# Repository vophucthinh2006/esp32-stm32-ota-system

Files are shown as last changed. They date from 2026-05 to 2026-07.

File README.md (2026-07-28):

# ESP32 to STM32 Dual-MCU OTA Update System

A robust dual-MCU Firmware Over-The-Air (OTA) update system. This project utilizes an ESP32 as a network-connected gateway that fetches firmware binaries from a GitHub repository via HTTPS and flashes them onto an STM32F103C8T6 target microcontroller via a custom bare-metal UART bootloader protocol.

---

## 1. Project Overview

This system provides a reliable, remote firmware deployment pipeline for distributed edge devices. The architecture clearly separates the network gateway layer from the core application execution layer:

* **ESP32 (Gateway):** Periodically polls GitHub using HTTPS HEAD requests, monitors the `ETag` header for remote binary changes, streams 128-byte chunk buffers over SSL, and acts as the UART Master to program the host.
* **STM32F103 (Application Host):** Runs a custom **Bare-Metal Bootloader** (direct register access) that verifies a 2-step handshake, erases designated internal flash pages, calculates 16-bit CRC on incoming packets, programs internal flash, and safely jumps to user application space.

---

## 2. Key Features & Implementation Achievements

* **Dynamic Update Detection:** Uses HTTP `ETag` tracking instead of full binary downloads to detect remote firmware updates, drastically reducing bandwidth and power consumption.
* **Cache-Busting Mechanism:** Appends a random `cache buster` parameter to query URLs to bypass proxy/CDN caching and guarantee fresh fetches.
* **Bare-Metal Reliability:** The STM32 bootloader is implemented entirely at the register level (No HAL, No LL, No RTOS), minimizing code footprint and eliminating library overhead.
* **Stream-Based Chunk Buffering:** Downloads and flashes firmware in 128-byte chunks, avoiding the need for large external flash/RAM storage.
* **Memory-Safe Padding:** Automates 128-byte alignment padding (`0xFF`) for non-full partial flash blocks at the end of the stream.
* **Hardware Status Indicators:** Dedicated LEDs provide real-time visual feedback (`LED_POWER`, `LED_NEW_VERSION`, `LED_LOADING`).

---

## 3. Hardware Overview & Pinout

### 3.1 Components & Modules
* **Gateway Microcontroller:** ESP32-DevKitC-32D.
* **Target Microcontroller:** STM32F103C8T6 (ARM Cortex-M3).
* **Power Management:** LM2596 Buck Converter Module (12V Battery Input → 5V System Power).
* **Power Control:** SW_SPDT Power Switch.
* **User Input:** SPST Push Button with RC filter (`C1 = 0.1µF`) for physical debouncing.

### 3.2 Pin Mapping

#### ESP32 Gateway Board:
| Pin Name | Function / Connection | Description |
| :--- | :--- | :--- |
| `IO32` | `LED_POWER` (`D1` via 220Ω) | Power-On Indicator |
| `IO17` | `LED_NEW_VERSION` (`D2` via 220Ω) | Remote update available on GitHub |
| `IO2` | `LED_LOADING` (`D3` via 220Ω) | Active flashing/erasing in progress |
| `IO4` | `SW1 Button` (Active-Low) | User trigger to start OTA update process |
| `TXD2` (`IO10`) | UART2 TX $\rightarrow$ STM32 RX | Serial Command & Payload Line |
| `RXD2` (`IO9`) | UART2 RX $\leftarrow$ STM32 TX | Serial ACK/NACK Response Line |

#### Target Communication Header (5-Pin Header):
| Pin | Function | Description |
| :--- | :--- | :--- |
| `1` | `VCC` | +5V Power Rail |
| `2` | `GND` | Ground Reference |
| `3` | `RxD` | UART Receive Line |
| `4` | `TxD` | UART Transmit Line |
| `5` | `Button` | Manual Boot Mode Trigger / Hardware Interlock |

---

## 4. Hardware Design & Schematics

### 4.1 Schematic Diagram
The custom carrier board schematic integrates power regulation, status LEDs, debounced input, and external headers.

<p align="center">
  ESP32 STM32 OTA System - Schematic
</p>

### 4.2 PCB Layout
Single-sided PCB design incorporating power planes, signal routing, and modular sub-board connections.

<p align="center">
  PCB Layout
</p>

---

## 5. Software Architecture & State Machines

### 5.1 System-Level Finite State Machine (End-to-End Workflow)
The complete interaction lifecycle between GitHub Cloud, ESP32 Gateway, and STM32 Target Microcontroller:

<p align="center">
  OTA Overall System State Machine
</p>

### 5.2 STM32 Bootloader Internal Operations
Detailed internal state processing, packet verification, and flash memory execution on the target STM32:

<p align="center">
  STM32 Bootloader Internal Execution Flow
</p>

---

## 6. UART Communication Protocol

All control frames and data packets transmitted from the ESP32 to the STM32 adhere to a structured protocol format:

### 6.1 Packet Structure
| Field | Size (Bytes) | Description / Value |
| :--- | :--- | :--- |
| **Start of Frame (SOF)** | 2 | Header Sync Bytes: `0xAA 0xBB` |
| **Command Code (CMD)** | 1 | `0x01` (START), `0x02` (ERASE), `0x03` (PROGRAM), `0x04` (JUMP) |
| **Data Length** | 1 | Payload byte length ($N \le 250$) |
| **Payload Data** | $N$ | Binary firmware slice or command parameters |
| **Checksum (CRC16)** | 2 | Big-Endian CCITT CRC-16 ($x^{16} + x^{12} + x^5 + 1$) |

### 6.2 Security Handshake Sequence
Before accepting flashing commands, the STM32 enforces a strict key validation handshake:
1. ESP32 sends `BL_UPDATE_KEY_1` (`0xCC`). STM32 validates and responds with `ACK` (`0x0A`).
2. ESP32 sends `BL_UPDATE_KEY_2` (`0xDD`). STM32 validates and responds with `ACK` (`0x0A`).
3. Upon completion, STM32 transitions to the verified bootloader receiving state.

### 6.3 Flashing Commands Breakdown
* `BL_START` (`0x01`): Resets internal flash write pointer (`FLASH_Page_Pointer`) to `APP_ADD_BASE` (`0x08002000`).
* `BL_ERASE` (`0x02`): Sequentially erases target application pages (Pages 8 to 63).
* `BL_PROGRAM` (`0x03`): Programs incoming 128-byte binary streams into Flash as 16-bit half-words and increments the memory pointer.
* `BL_JUMP` (`0x04`): Disables global interrupts, re-maps Vector Table (`SCB_VTOR` to `0x08002000`), sets Main Stack Pointer (`_Set_MSP`), and jumps to User Application Execution.

---

## 7. Flash Memory Mapping (STM32F103C8T6)

The internal 64KB Flash memory space is divided to segregate the immutable bootloader from the upgradable application space:

<p align="center">
  STM32 Bootloader Internal FLash Memory Mapping
</p>

---

## 8. Demo Video
Below is a short demo video illustrating the end-to-end OTA update process:

▶️ [ESP32 to STM32 Dual-MCU OTA Update - Demo Video](https://youtu.be/XsSUUxfZz8Y?si=K6gj_BpSvMdLIf3Q)

---

## 9. Build and Flash
**ESP32 Gateway Firmware**
* **Framework: ESP-IDF / Arduino Core for ESP32.**

* **Libraries:** WiFiClientSecure, HTTPClient.

**STM32 Bootloader**
* **Toolchain:** arm-none-eabi-gcc.

* **Build System:** CMake.

* **Programmer:** ST-Link V2.

* **Development Style:** Bare-metal direct register programming (No HAL / LL libraries used).

---

## 10. Performance & System Trade-offs
* **Baud Rate Selection (9600 bps):** Chosen to guarantee noise-immune, zero-error serial data transfer over unshielded wires between the gateway and target board without needing hardware RTS/CTS flow control.

* **Stream Buffering vs. External Storage:** Processing firmware in small 128-byte RAM buffers eliminates the physical footprint, cost, and power overhead of an external SPI Flash chip or SD card module.

* **Single-Bank Flashing:** Prioritizes maximum flash allocation for user applications (~56KB available out of 64KB) over dual-bank storage, relying on CRC checks and handshake verification to ensure update integrity.

---

## 11. Limitations and Future Improvements
* **Dual-Bank Architecture:** Adding external SPI flash to support rollback in case of power interruption during programming.

* **Hardware Reset Line:** Wiring an ESP32 GPIO directly to the STM32 NRST pin for automated hard-resets into bootloader mode.

* **Firmware Encryption:** Implementing AES-128/256 payload decryption on the STM32 to secure firmware against eavesdropping.

---

## 12. Author
**Author:** Vo Phuc Thinh

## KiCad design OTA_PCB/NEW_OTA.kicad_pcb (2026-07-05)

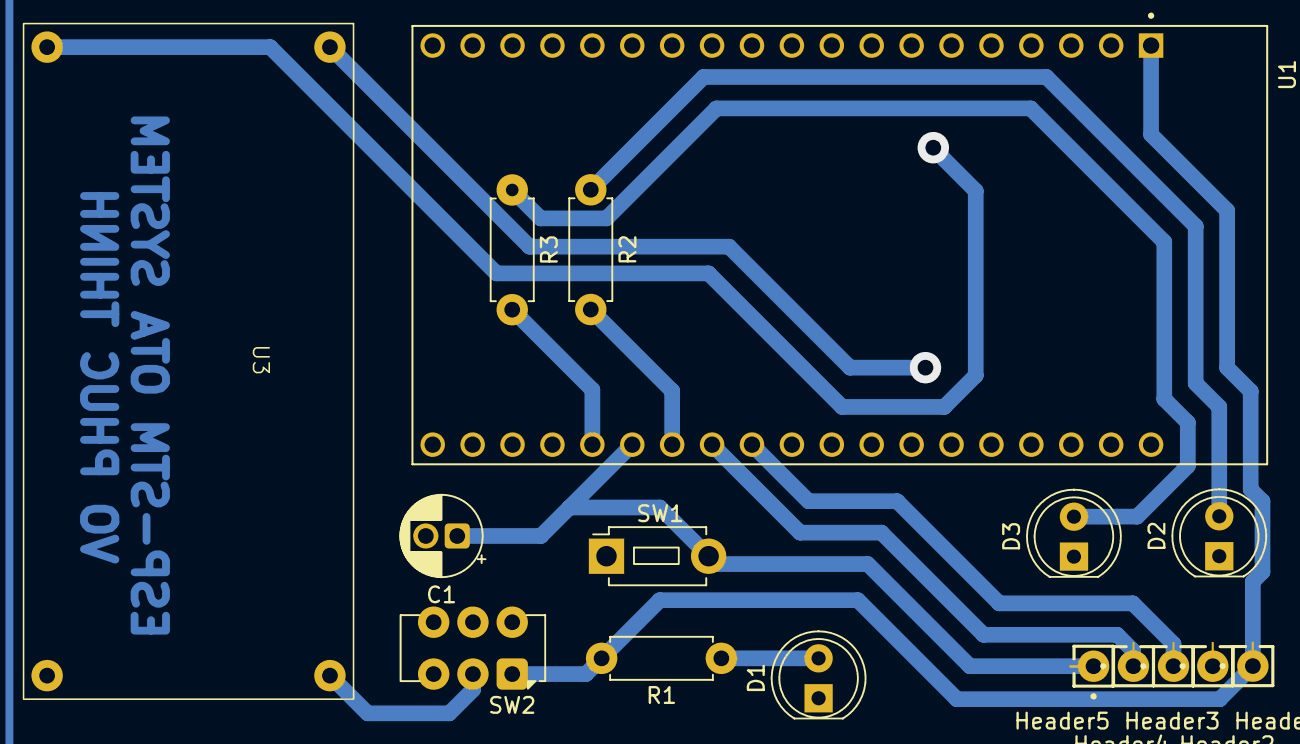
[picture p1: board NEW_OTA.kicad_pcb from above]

Board: 2 copper layers, 16 parts (0 on the bottom side), 11 nets.

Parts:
C1: 0.1uF; CP_Radial_D5.0mm_P2.00mm
D1, D2, D3: LED; LED_D5.0mm_Clear
Header1: VCC; SAMTEC_MTLW-101-08-S-S-330
Header2: GND; SAMTEC_MTLW-101-08-S-S-330
Header3: RXD; SAMTEC_MTLW-101-08-S-S-330
Header4: TXD; SAMTEC_MTLW-101-08-S-S-330
Header5: Button; SAMTEC_MTLW-101-08-S-S-330
R1, R2, R3: 220; R_Axial_DIN0207_L6.3mm_D2.5mm_P7.62mm_Horizontal
SW1: Button; SW_PUSH_1P1T_6x3.5mm_H4.3_APEM_MJTP1243
SW2: SW_SPDT; SW_CK_JS202011AQN_DPDT_Angled
U1: ESP32-DEVKITC-32D; MODULE_ESP32-DEVKITC-32D
U3: LM2596-Buck-Converter-Module; LM2596 Buck Converter Module

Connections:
/Button: C1.1, Header5.01 (01_01), SW1.1, U1.J3-14 (IO0)
/Source: SW2.2 (B), U3.1 (OUT+)
/UART2_RX: Header4.01 (01_01), U1.J3-12 (IO16)
/UART2_TX: Header3.01 (01_01), U1.J3-11 (IO17)
/VCC: Header1.01 (01_01), R1.2, SW2.1 (A), U1.J2-1 (3V3)
GND: C1.2, D1.1 (K), D2.1 (K), D3.1 (K), Header2.01 (01_01), SW1.2, U1.J2-14 (GND1), U1.J3-1 (GND3), U1.J3-7 (GND2), U3.2 (OUT-)
unnamed: D1.2 (A), R1.1
unnamed: D2.2 (A), R2.1
unnamed: D3.2 (A), R3.1
unnamed: R3.2, U1.J3-15 (IO2)
unnamed: R2.2, U1.J3-13 (IO4)

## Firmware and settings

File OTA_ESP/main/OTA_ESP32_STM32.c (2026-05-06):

#include <stdio.h>
#include <string.h> 
#include "freertos/FreeRTOS.h"
#include "freertos/task.h"
#include "driver/gpio.h"
#include "driver/uart.h"
#include "esp_random.h"
#include "esp_log.h"
#include "WIFI.h"
#include "HTTP.h"
#include "ESP_BOOTLOADER.h"

static const char *TAG = "OTA_MAIN";

#define TXD_PIN          GPIO_NUM_17
#define RXD_PIN          GPIO_NUM_16
#define UART_PORT_NUM    UART_NUM_2
#define BUTTON_PIN       GPIO_NUM_0
#define LED_NEW_VERSION  GPIO_NUM_4
#define LED_LOADING      GPIO_NUM_2

static uint8_t ota_buffer[128];
static size_t ota_buf_idx = 0;
static char current_server_etag[64] = "";
static char last_applied_etag[64] = "";
static bool is_new_version_available = false;

void init_uart_bootloader() {
    uart_config_t cfg = {
        .baud_rate = 9600,
        .data_bits = UART_DATA_8_BITS,
        .parity = UART_PARITY_DISABLE,
        .stop_bits = UART_STOP_BITS_1,
        .flow_ctrl = UART_HW_FLOWCTRL_DISABLE
    };
    uart_param_config(UART_PORT_NUM, &cfg);
    uart_set_pin(UART_PORT_NUM, TXD_PIN, RXD_PIN, -1, -1);
    uart_driver_install(UART_PORT_NUM, 1024, 0, 0, NULL, 0);

    gpio_config_t io_conf = {
        .pin_bit_mask = (1ULL << BUTTON_PIN),
        .mode = GPIO_MODE_INPUT,
        .pull_up_en = GPIO_PULLUP_ENABLE,
    };
    gpio_config(&io_conf);
}
void init_gpio_leds() {
    gpio_config_t led_conf = {
        .pin_bit_mask = (1ULL << LED_NEW_VERSION) | (1ULL << LED_LOADING),
        .mode = GPIO_MODE_OUTPUT,
        .pull_down_en = GPIO_PULLDOWN_DISABLE,
        .pull_up_en = GPIO_PULLUP_DISABLE,
    };
    gpio_config(&led_conf);
    
    gpio_set_level(LED_NEW_VERSION, 0);
    gpio_set_level(LED_LOADING, 0);
}

esp_err_t my_ota_data_cb(uint8_t *data, size_t len) {
    for (size_t i = 0; i < len; i++) {
        ota_buffer[ota_buf_idx++] = data[i];

        if (ota_buf_idx == 128) {
            if (BL_Send_Program(ota_buffer, 128) != ESP_OK) {
                return ESP_FAIL;
            }
            ota_buf_idx = 0;
        }
    }
    ESP_LOGI(TAG, "Received %d bytes from stream...", (int)len);
    return ESP_OK; 
}

esp_err_t OTA_Finalize_Padding() {
    if (ota_buf_idx > 0) {
        memset(&ota_buffer[ota_buf_idx], 0xFF, 128 - ota_buf_idx);
        if (BL_Send_Program(ota_buffer, 128) != ESP_OK) {
            return ESP_FAIL;
        }
        ota_buf_idx = 0;
    }
    return ESP_OK;
}

void run_ota_process() {
    gpio_set_level(LED_NEW_VERSION, 0);
    gpio_set_level(LED_LOADING, 0);

    ESP_LOGW(TAG, "OTA process starting...");
    
    if (BL_Handshake() != ESP_OK) {
        ESP_LOGE(TAG, "STM32 does not respond!");
        return;
    }
    if (BL_Send_Start() != ESP_OK) {
        ESP_LOGE(TAG, "Start CMD failed!");
        return;
    }
    if (BL_Send_Erase_App(25) != ESP_OK) {
        ESP_LOGE(TAG, "Erase Flash failed!");
        return;
    }

    gpio_set_level(LED_LOADING, 1);
    ESP_LOGI(TAG, "STM32 is ready to receive Data.");

    const char *base_url = "https://raw.githubusercontent.com/vophucthinh2006/esp32-stm32-ota-system/main/BOOTLOADER_TESTING.bin";
    char url_with_cache_buster[256];
    snprintf(url_with_cache_buster, sizeof(url_with_cache_buster), "%s?v=%lu", base_url, (unsigned long)esp_random());
    
    ESP_LOGI(TAG, "Requesting URL: %s", url_with_cache_buster);

    if (http_download_stream(url_with_cache_buster, my_ota_data_cb) == ESP_OK) {
        if (OTA_Finalize_Padding() == ESP_OK) {
            vTaskDelay(pdMS_TO_TICKS(100)); 
            if (BL_Send_Jump() == ESP_OK) {
                gpio_set_level(LED_LOADING, 0);
                ESP_LOGI(TAG, "OTA process successful! STM32 is starting new app.");
                strcpy(last_applied_etag, current_server_etag);
                is_new_version_available = false;
            }
        } else {
            gpio_set_level(LED_LOADING, 0);
            ESP_LOGE(TAG, "Padding process failed!");
        }
    } else {
        gpio_set_level(LED_LOADING, 0);
        ESP_LOGE(TAG, "OTA process failed!");
    }
}

void ota_control_task(void *pv) {
    const char *base_url = "https://raw.githubusercontent.com/vophucthinh2006/esp32-stm32-ota-system/main/BOOTLOADER_TESTING.bin";
    char check_url[256];
    
    while(1) {
        if (wifi_is_connected()) {
            char new_etag[64] = "";

            snprintf(check_url, sizeof(check_url), "%s?nocache=%lu", base_url, (unsigned long)esp_random());

            if (http_get_etag(check_url, new_etag) == ESP_OK) {

                if (strcmp(new_etag, last_applied_etag) != 0) {

                    if (strlen(new_etag) > 0) {
                        strcpy(current_server_etag, new_etag);
                        is_new_version_available = true;
                        gpio_set_level(LED_NEW_VERSION, 1);
                        ESP_LOGW(TAG, "NEW VERSION FOUND! ETag: %s", new_etag);
                    }
                } else {

                    gpio_set_level(LED_NEW_VERSION, 0);
                    is_new_version_available = false; 
                }
            }
        }
        vTaskDelay(pdMS_TO_TICKS(10000)); 
    }
}
void check_for_updates() {
    const char *base_url = "https://raw.githubusercontent.com/vophucthinh2006/esp32-stm32-ota-system/main/BOOTLOADER_TESTING.bin";
    char check_url[256];
    char new_etag[64] = "";

    if (wifi_is_connected()) {
        snprintf(check_url, sizeof(check_url), "%s?nocache=%lu", base_url, (unsigned long)esp_random());
        
        if (http_get_etag(check_url, new_etag) == ESP_OK) {
            if (strcmp(new_etag, last_applied_etag) != 0) {
                if (strlen(new_etag) > 0) {
                    strcpy(current_server_etag, new_etag);
                    is_new_version_available = true;
                    gpio_set_level(LED_NEW_VERSION, 1);
                    ESP_LOGW(TAG, "CHECK: NEW VERSION FOUND! ETag: %s", new_etag);
                }
            } else {
                gpio_set_level(LED_NEW_VERSION, 0);
                is_new_version_available = false;
                ESP_LOGI(TAG, "CHECK: Device is up to date.");
            }
        }
    }
}

void app_main(void) {

    init_uart_bootloader();
    init_gpio_leds();
    vTaskDelay(pdMS_TO_TICKS(1000));

    wifi_init_sta("thinhhh", "Thinh0602,");
    while(!wifi_is_connected()) {
        vTaskDelay(pdMS_TO_TICKS(500));
    }
    ESP_LOGI(TAG, "WiFi is ready.");

    xTaskCreate(ota_control_task, "ota_control_task", 4096, NULL, 5, NULL);

    uint8_t incoming;
    while(1) {

        if (gpio_get_level(BUTTON_PIN) == 0) {
            vTaskDelay(pdMS_TO_TICKS(50)); // Debounce
            if (gpio_get_level(BUTTON_PIN) == 0) {
                if (is_new_version_available) {
                    run_ota_process();
                    check_for_updates();
                } else {
                    ESP_LOGI(TAG, "No new version found.");
                }
            }
        }

        // Read log from STM32 for debugging
        if (uart_read_bytes(UART_PORT_NUM, &incoming, 1, pdMS_TO_TICKS(10)) > 0) {
            putchar(incoming);
            fflush(stdout);
        }
        
        vTaskDelay(pdMS_TO_TICKS(1)); 
    }
}

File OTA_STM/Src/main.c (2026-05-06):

#include "RCC.h"
#include "UART.h"
#include "STM_BOOTLOADER.h"

int main(void) {
    RCC_Enable(RCC_PORTA);
    GPIO_Config(GPIO_PORTA, 0, GPIO_CNF_IN_PU, GPIO_MODE_IN);
    for(volatile int i = 0; i < 50000; i++);

    if (GPIO_Read_Pin(GPIO_PORTA, 0) == 1) BL_JumpToApplication();

    RCC_Enable(RCC_UART1);
    UART_Init(UART1, 9600, UART_WORD_LENGTH_8);

    _Interrupts_Disable();
    while (1) {
        if (bl_wait_key != BL_WAIT_KEY_VERIFIED) {
            if (UART_HasData(UART1)) {
            	bl_update_signal = UART_Receive(UART1);
                BL_Update_Verify();
            }
        }
        else {
            if (UART_HasData(UART1)) {
                if (UART1_DR == 0xAA) {
                    BL_Get_Packet();
                    BL_Packet_Handler();
                }
            }
        }
    }
}

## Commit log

2026-05-06 Fix: Remove submodule and successfully add BOOTLOADER source files
    [STM_BOOTLOADER.c, main.c]
2026-07-05 Update firmware 2026-07-05 07:22:28
    [NEW_OTA.kicad_pcb]
2026-07-28 Add Schematic and PCB Layout
2026-07-28 Update Schematic and PCB Layout
2026-07-28 Change PCB Layout image source and style
    Updated image source path and added styling.
2026-07-28 Simplify PCB layout image in README
    Removed inline styling from PCB layout image.
